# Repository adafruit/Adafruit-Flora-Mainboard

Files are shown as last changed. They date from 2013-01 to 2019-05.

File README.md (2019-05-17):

# Adafruit Flora Mainboard PCB Files
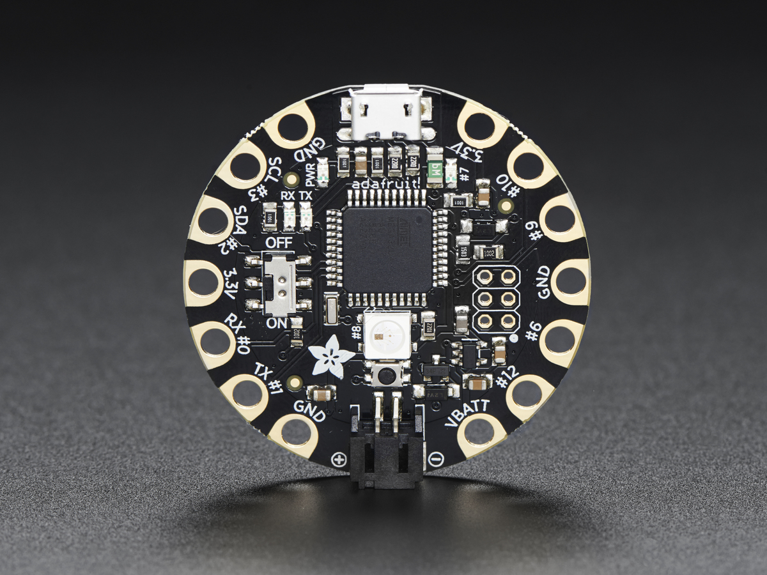
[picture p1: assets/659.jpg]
<a href="http://www.adafruit.com/products/659"><br/>
Click here to purchase one from the Adafruit shop</a>

FLORA is Adafruit's fully-featured wearable electronics platform. It's a round, sewable, Arduino-compatible microcontroller designed to empower amazing wearables projects.FLORA comes with Adafruit's support, tutorials and projects. Check out dozens of FLORA tutorials on the Adafruit Learning System, with more added all the time!

The FLORA is small (1.75" diameter, weighing 4.4 grams). The FLORA family also has the best stainless steel threads, sensors, GPS modules and chainable LED NeoPixels, perfect accessories for the FLORA main board. 

The FLORA has built-in USB support. Built in USB means you plug it in to program it, it just shows up - all you need is a Micro-B USB cable, no additional purchases are needed! We have a modified version of the Arduino IDE so Mac & Windows users can get started fast - or with the new 1.6.4+ Arduino IDE, it takes only a few seconds to add Flora-support. The FLORA has USB HID support, so it can act like a mouse or keyboard to attach directly to computers.

This is the PCB for the Adafruit Flora Mainboard. The format is EagleCAD schematic and board layout
- http://adafruit.com/products/659

### License

Adafruit invests time and resources providing this open source design, please support Adafruit and open-source hardware by purchasing products from [Adafruit](https://www.adafruit.com)!

All text above must be included in any redistribution

Designed by Limor Fried/Ladyada for Adafruit Industries.
Creative Commons Attribution/Share-Alike, all text above must be included in any redistribution. 
See license.txt for additional information.

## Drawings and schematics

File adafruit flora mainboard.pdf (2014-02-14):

### GND

10uF

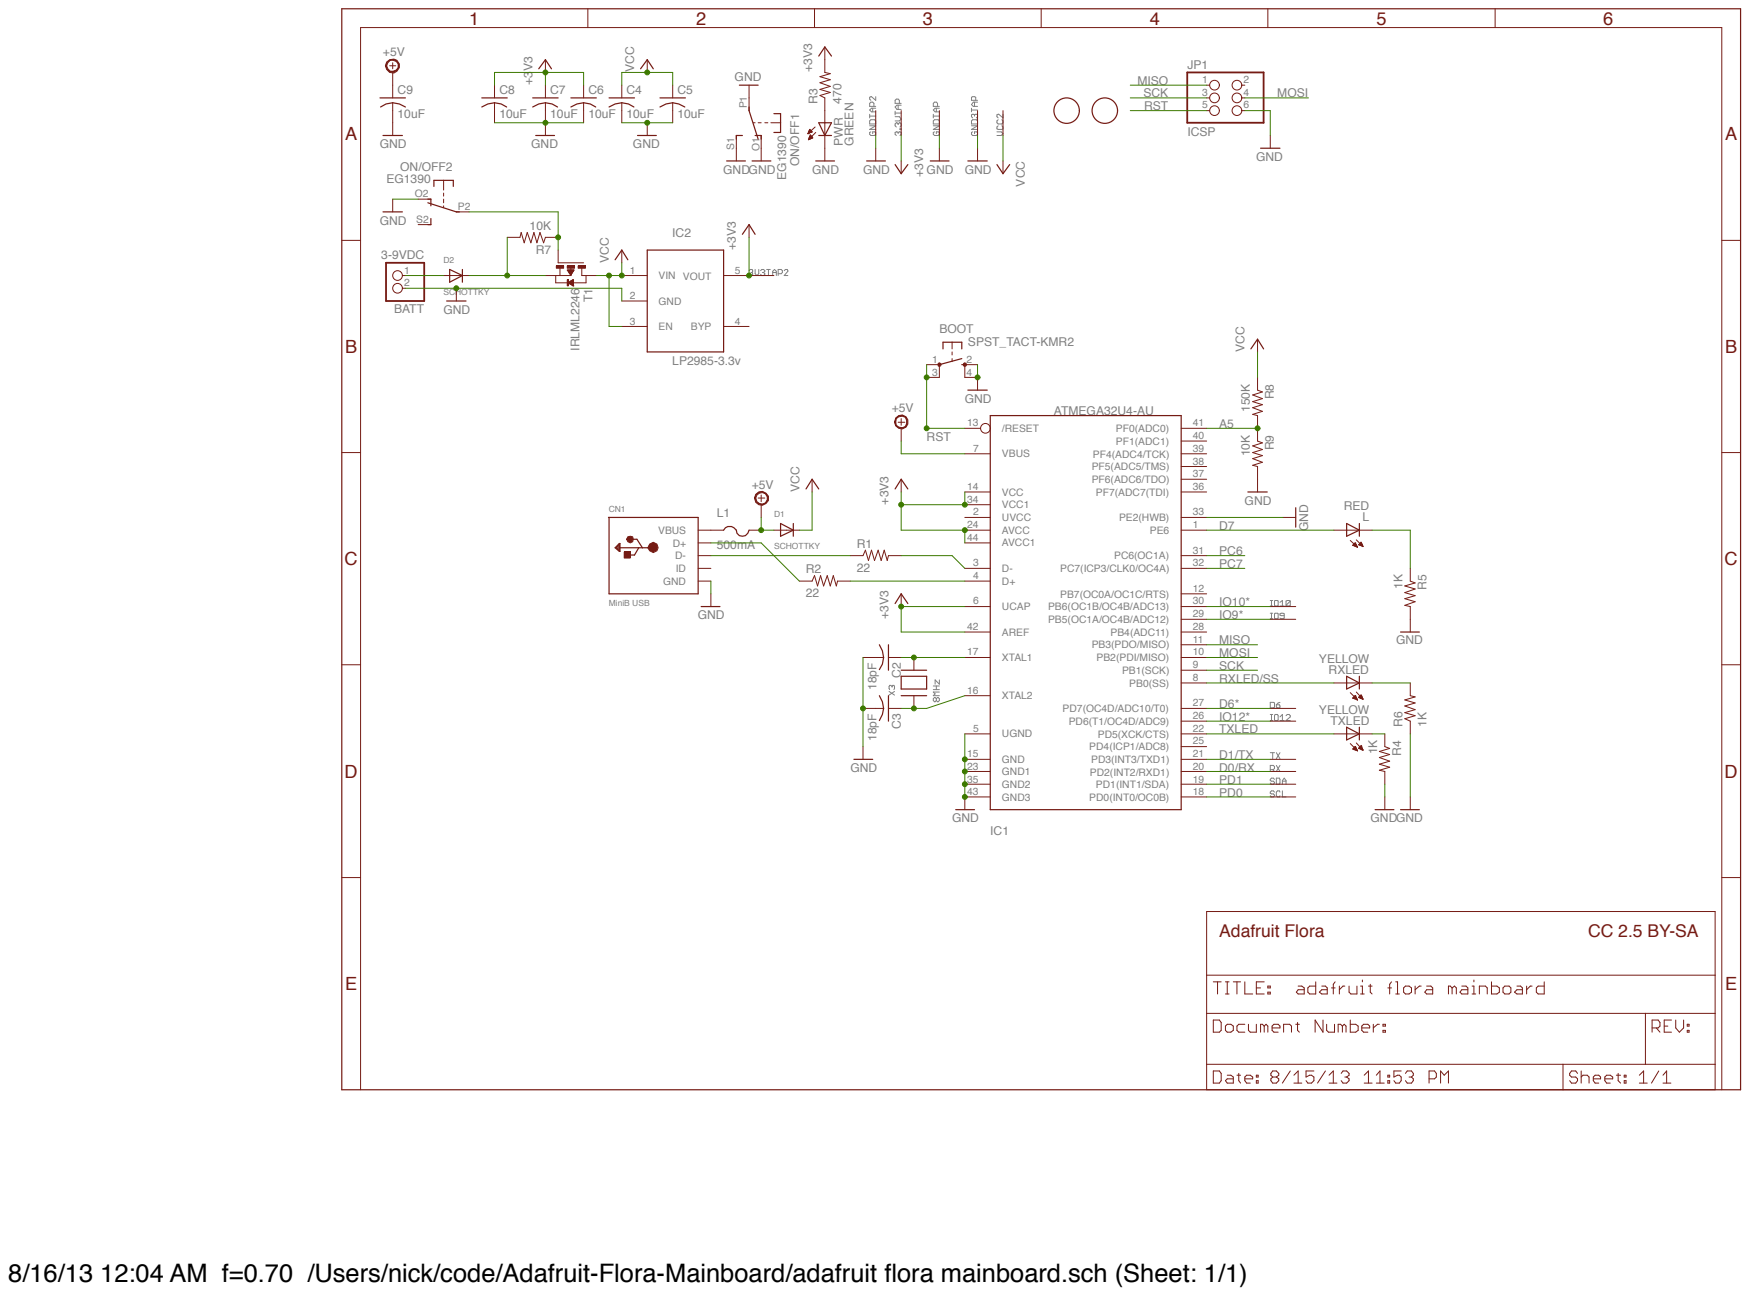
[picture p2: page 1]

GND 15 | D1/TX
GND1 23 | D0/RX

8/16/13 12:04 AM f=0.70 /Users/nick/code/Adafruit-Flora-Mainboard/adafruit flora mainboard.sch (Sheet: 1/1)

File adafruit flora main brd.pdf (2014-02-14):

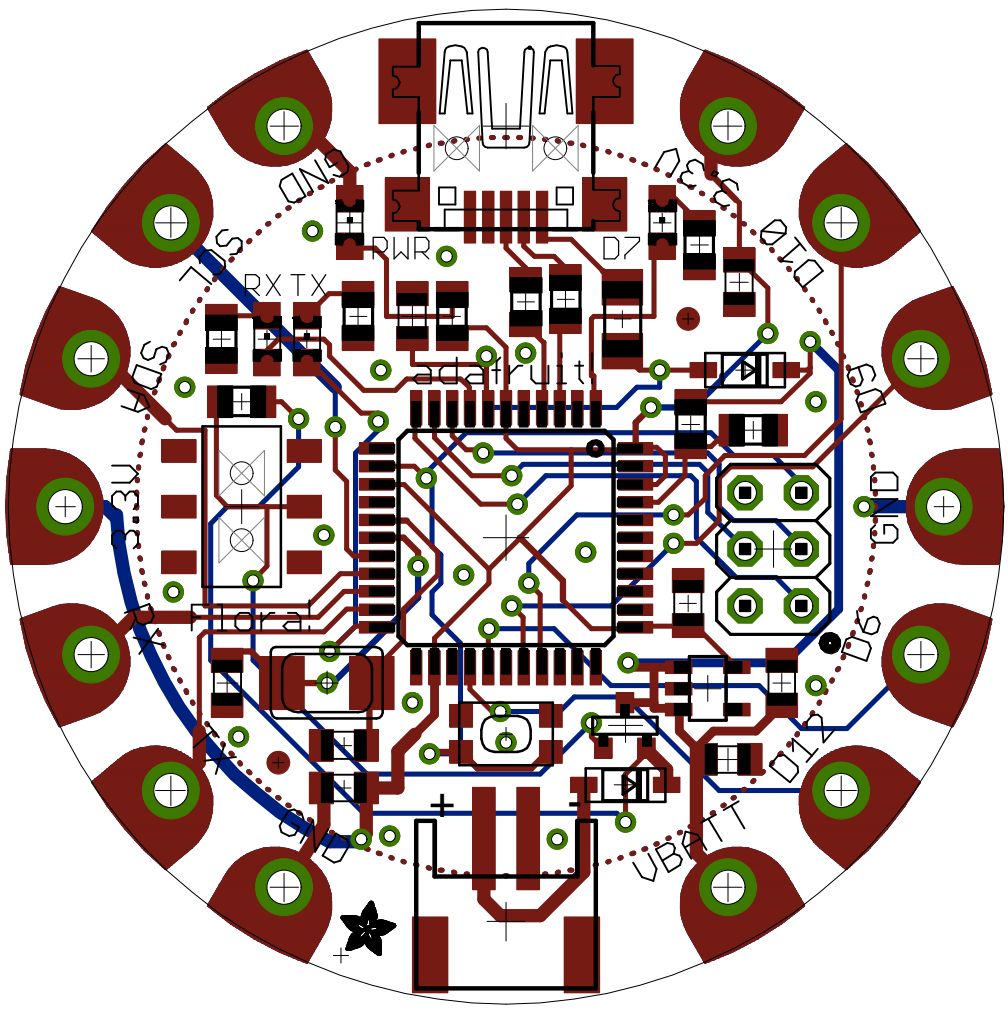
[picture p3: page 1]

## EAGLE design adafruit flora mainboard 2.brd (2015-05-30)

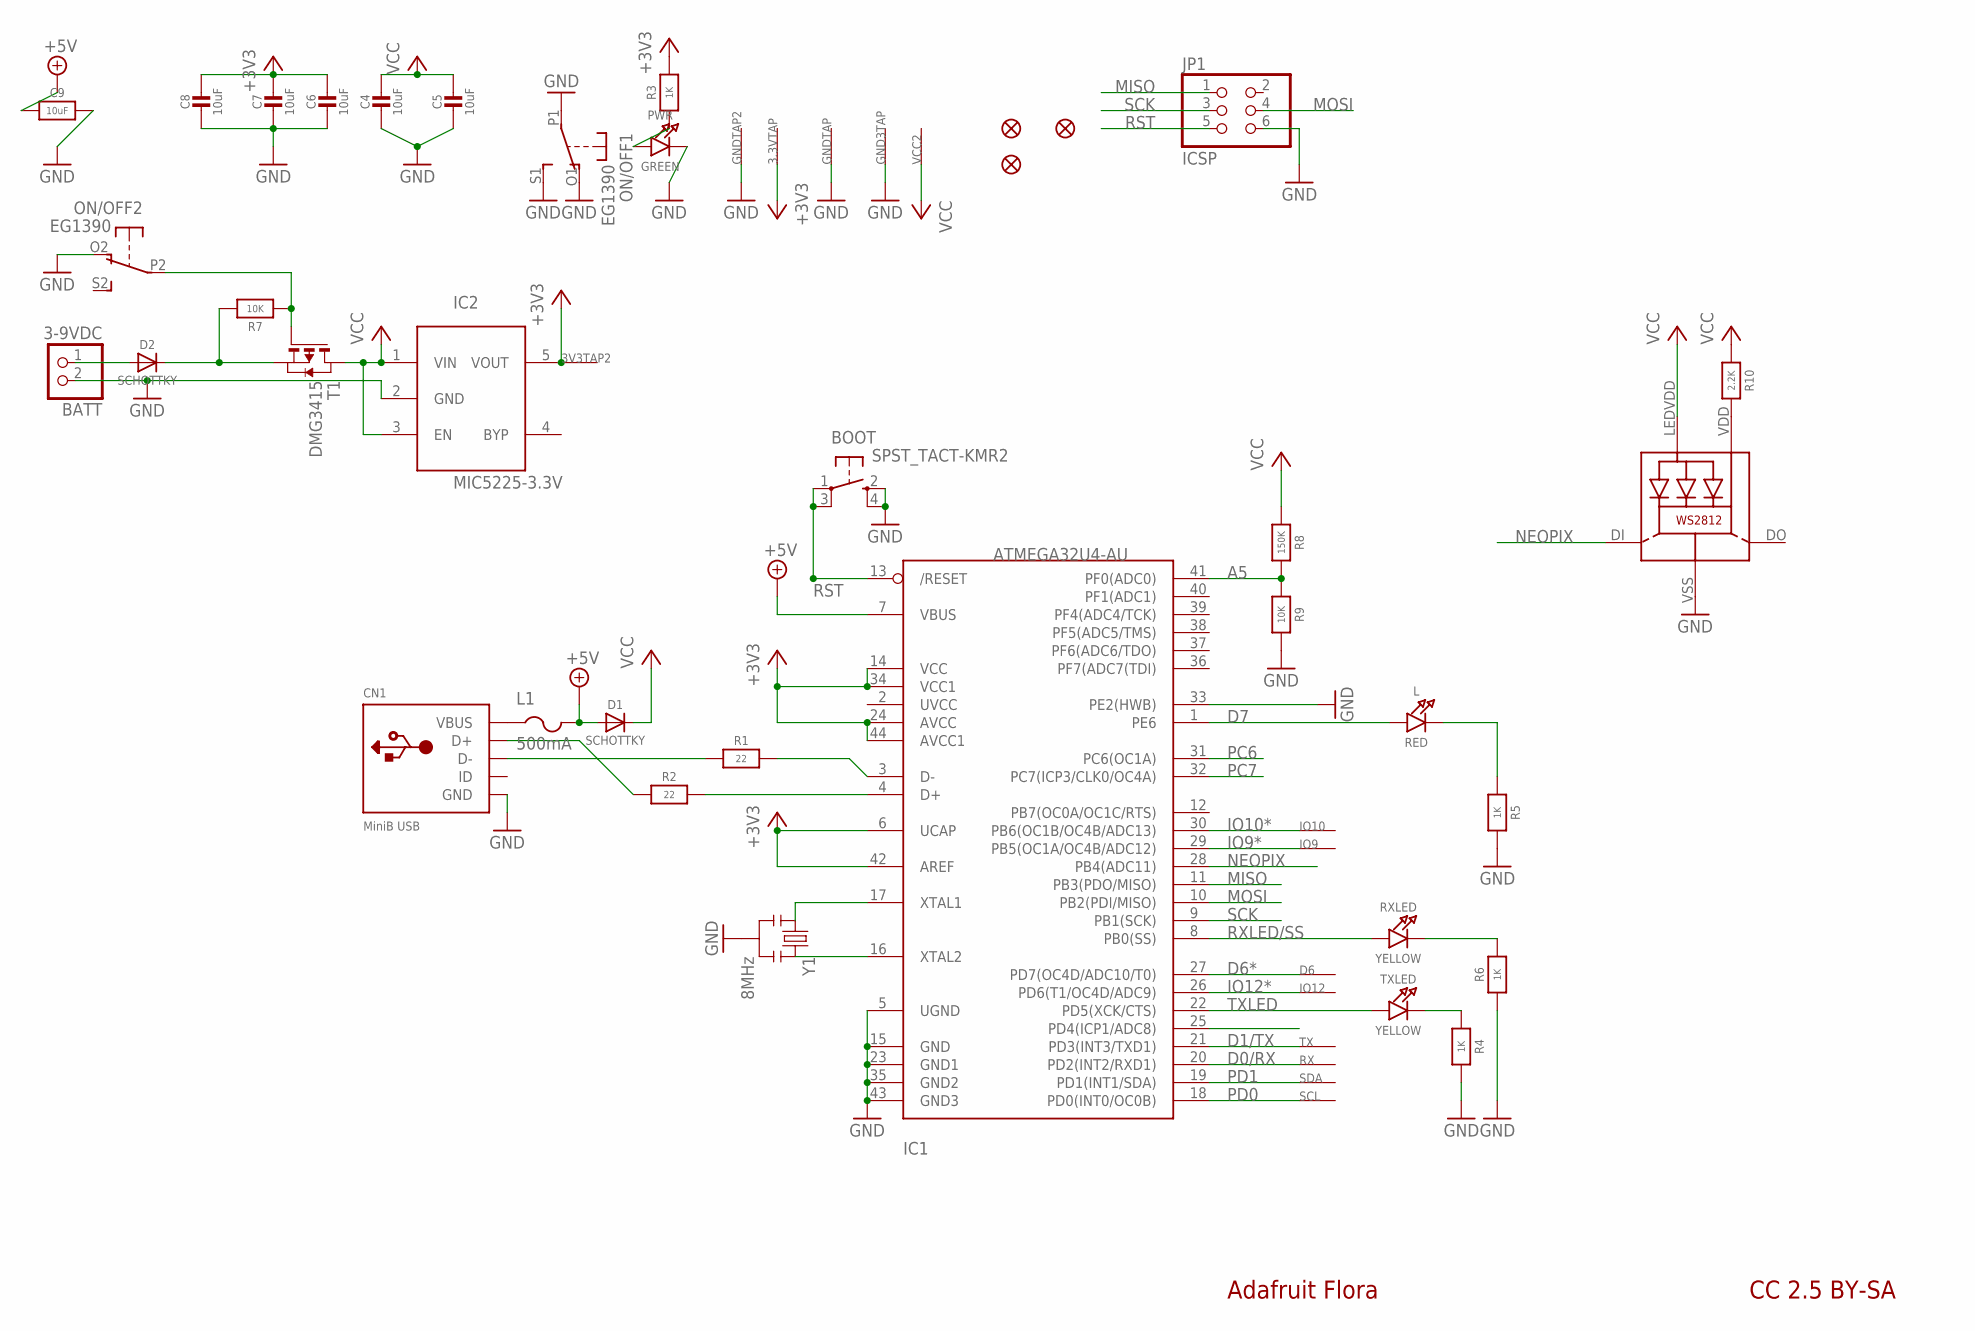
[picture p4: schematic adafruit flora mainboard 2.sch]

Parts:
3.3VTAP, 3V3TAP2: SEWTAP-2.0IN; SEWINGTAP_2.0
BATT: 3-9VDC; JST-PH-2-SMT-RA
BOOT: SPST_TACT-KMR2; KMR2
C4, C5, C6, C7, C8: 10uF; 0805-NO
C9: 10uF; _0805MP
CN1: MiniB USB; 4UCONN_20329
D1, D2: SCHOTTKY; SOD-123
D6: SEWTAP-2.0IN; SEWINGTAP_2.0
GND3TAP: SEWTAP-2.0IN; SEWINGTAP_2.0
GNDTAP, GNDTAP2: SEWTAP-2.0IN; SEWINGTAP_2.0
IC1: ATMEGA32U4-AU; TQFP44
IC2: MIC5225-3.3V; SOT23-5L
IO9, IO10, IO12: SEWTAP-2.0IN; SEWINGTAP_2.0
JP1: ICSP; 2X03
L: RED; CHIPLED_0805_NOOUTLINE
L1: 500mA; R1206
LED1: WS2812
ON/OFF: EG1390
PWR: GREEN; CHIPLED_0805_NOOUTLINE
R1, R2: 22; 0805-NO
R3, R4: 1K; _0805MP
R5, R6: 1K; 0805-NO
R7: 10K; _0805MP
R8: 150K; 0805-NO
R9: 10K; 0805-NO
R10: 2.2K; 0805-NO
RX: SEWTAP-2.0IN; SEWINGTAP_2.0
RXLED: YELLOW; CHIPLED_0805_NOOUTLINE
SCL: SEWTAP-2.0IN; SEWINGTAP_2.0
SDA: SEWTAP-2.0IN; SEWINGTAP_2.0
T1: DMG3415; SOT-23
TX: SEWTAP-2.0IN; SEWINGTAP_2.0
TXLED: YELLOW; CHIPLED_0805_NOOUTLINE
U$2, U$3, U$6: FIDUCIAL""; FIDUCIAL_1MM
VCC2: SEWTAP-2.0IN; SEWINGTAP_2.0
Y1: 8MHz; RESONATOR-SMD

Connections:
+3V3: 3.3VTAP.P$1, 3V3TAP2.P$1, C6.1, C7.1, C8.1, IC1.6 (UCAP), IC1.14 (VCC), IC1.24 (AVCC), IC1.34 (VCC1), IC1.42 (AREF), IC1.44 (AVCC1), IC2.5 (VOUT), R3.2
+5V: C9.1, D1.A, IC1.7 (VBUS), L1.2
A5: IC1.41 (PF0(ADC0)), R8.2, R9.1
D0/RX: IC1.20 (PD2(INT2/RXD1)), RX.P$1
D1/TX: IC1.21 (PD3(INT3/TXD1)), TX.P$1
D6*: D6.P$1, IC1.27 (PD7(OC4D/ADC10/T0))
D7: IC1.1 (PE6), L.A
GND: BATT.2 (1), BOOT.2 (S), BOOT.4 (S1), C4.2, C5.2, C6.2, C7.2, C8.2, C9.2, CN1.BASE@1 (GND), CN1.BASE@2 (GND), CN1.GND, CN1.SPRT@1 (GND), CN1.SPRT@2 (GND), CN1.SPRT@3 (GND), CN1.SPRT@4 (GND), GND3TAP.P$1, GNDTAP.P$1, GNDTAP2.P$1, IC1.5 (UGND), IC1.15 (GND), IC1.23 (GND1), IC1.33 (PE2(HWB)), IC1.35 (GND2), IC1.43 (GND3), IC2.2 (GND), JP1.6, LED1.VSS (GND), ON/OFF.O1 (O), ON/OFF.O2 (O), ON/OFF.P1, ON/OFF.S1 (S), PWR.C, R4.2, R5.2, R6.1, R9.2, Y1.2
IO9*: IC1.29 (PB5(OC1A/OC4B/ADC12)), IO9.P$1
IO10*: IC1.30 (PB6(OC1B/OC4B/ADC13)), IO10.P$1
IO12*: IC1.26 (PD6(T1/OC4D/ADC9)), IO12.P$1
MISO: IC1.11 (PB3(PDO/MISO)), JP1.1
MOSI: IC1.10 (PB2(PDI/MISO)), JP1.4
unnamed: PWR.A, R3.1
unnamed: CN1.D+, R2.1
unnamed: IC1.3 (D-), R1.2
unnamed: IC1.4 (D+), R2.2
unnamed: CN1.D-, R1.1
unnamed: D2.C, R7.2, T1.2 (S)
unnamed: BATT.1 (2), D2.A
unnamed: IC1.17 (XTAL1), Y1.1
unnamed: IC1.16 (XTAL2), Y1.3
unnamed: L.C, R5.1
unnamed: R4.1, TXLED.C
unnamed: R6.2, RXLED.C
unnamed: ON/OFF.P2, R7.1, T1.3 (G)
unnamed: LED1.VDD, R10.2
NEOPIX: IC1.28 (PB4(ADC11)), LED1.DI
PC6: IC1.31 (PC6(OC1A))
PC7: IC1.32 (PC7(ICP3/CLK0/OC4A))
PD0: IC1.18 (PD0(INT0/OC0B)), SCL.P$1
PD1: IC1.19 (PD1(INT1/SDA)), SDA.P$1
RST: BOOT.1, BOOT.3 (P1), IC1.13 (/RESET), JP1.5
RXLED/SS: IC1.8 (PB0(SS)), RXLED.A
SCK: IC1.9 (PB1(SCK)), JP1.3
TXLED: IC1.22 (PD5(XCK/CTS)), TXLED.A
VBUS: CN1.VBUS, L1.1
VCC: C4.1, C5.1, D1.C, IC2.1 (VIN), IC2.3 (EN), LED1.LEDVDD, R8.1, R10.1, T1.1 (D), VCC2.P$1

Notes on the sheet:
Adafruit Flora
CC 2.5 BY-SA

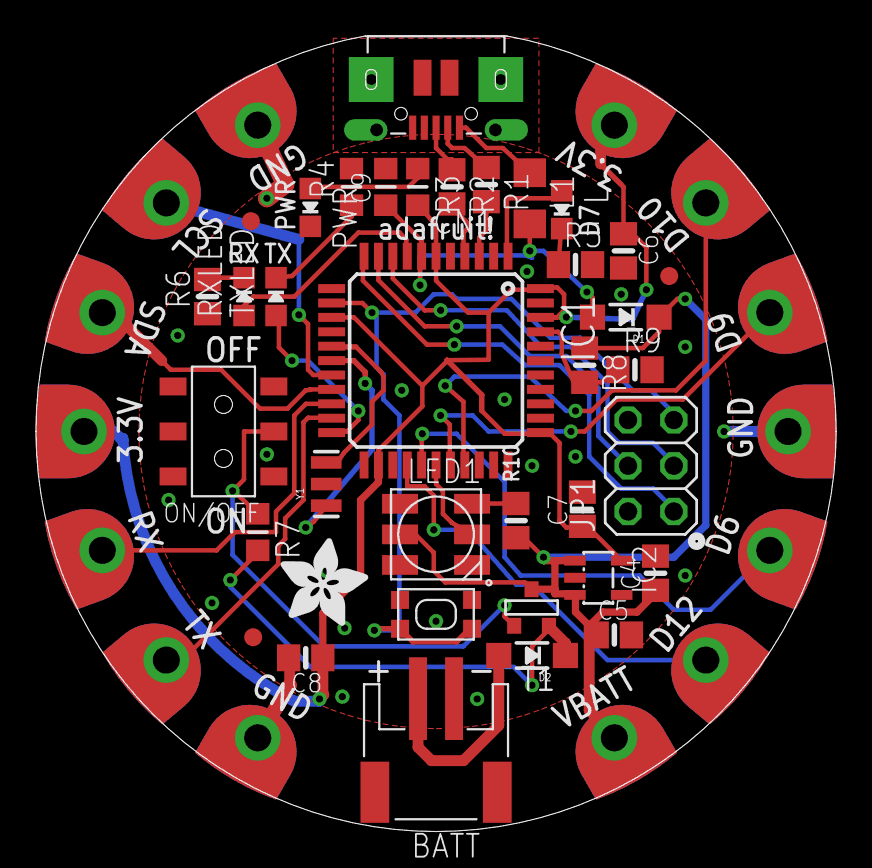
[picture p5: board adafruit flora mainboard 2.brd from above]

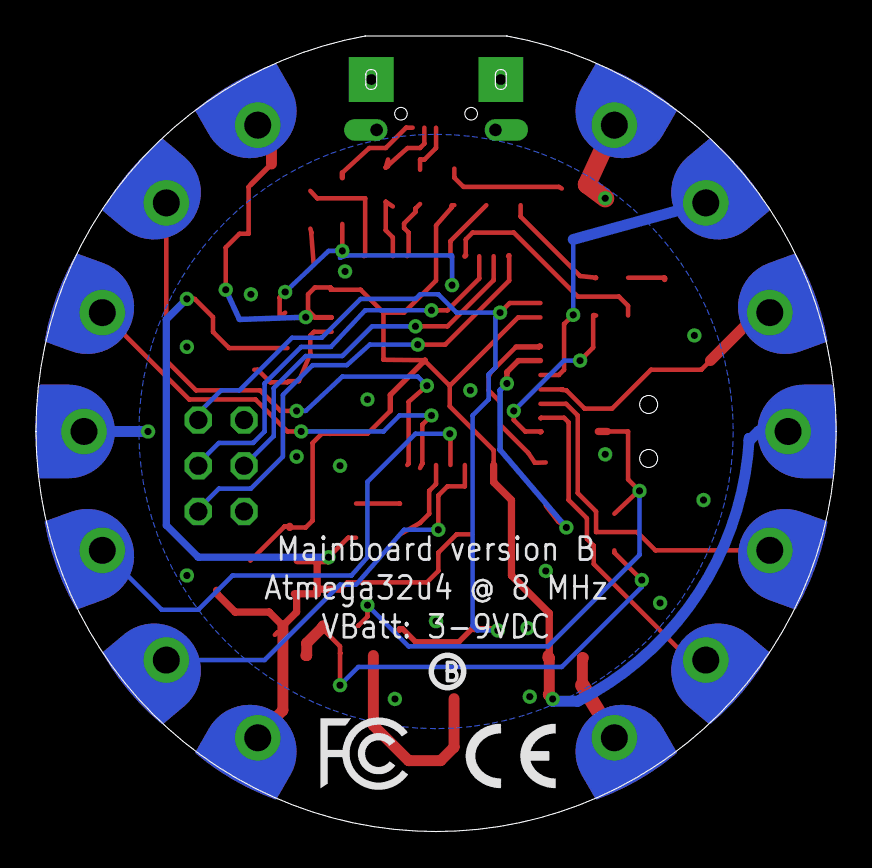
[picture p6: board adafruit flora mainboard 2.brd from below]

Board: 2 copper layers, 44.5 x 44.2 mm, 55 parts (4 on the bottom side), 36 nets.

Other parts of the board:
U$1: ADAFRUIT_5MM
U$4: FLORAMED
U$5: PCBFEAT-REV-040
U$7: SYMBOL_FCC_5MM
U$8: SYMBOL_CE_5MM

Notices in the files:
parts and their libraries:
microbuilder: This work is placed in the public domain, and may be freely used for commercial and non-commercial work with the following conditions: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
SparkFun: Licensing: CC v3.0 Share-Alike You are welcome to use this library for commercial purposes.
